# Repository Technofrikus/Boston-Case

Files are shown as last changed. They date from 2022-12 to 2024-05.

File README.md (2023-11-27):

# Boston-Case
Printable Case for the Boston keyboard, based on the metal case design of the original

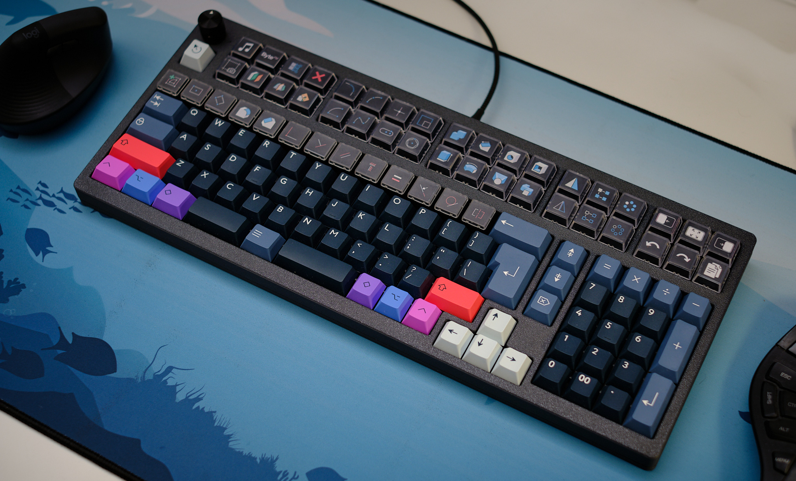
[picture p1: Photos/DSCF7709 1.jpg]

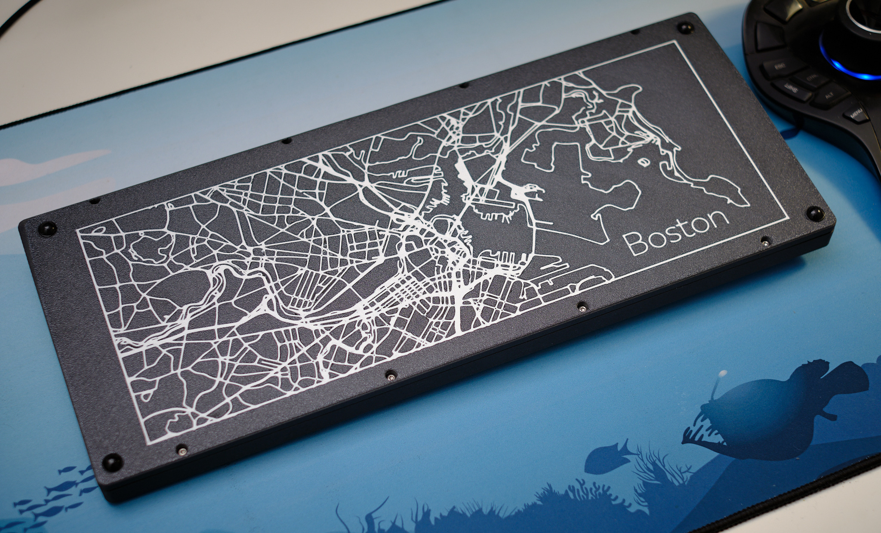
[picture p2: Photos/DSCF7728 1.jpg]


---
### About the Boston

[The Boston](https://github.com/bluepylons/Boston) is a compact 120% keyboard made by Pylon. There was never a real GB of the metal case, so Pylon was so very kind and opensourced the complete Board. There was a GB of a case specifically designed for 3D printing, but I didnt like the design and compromise of a split case.

So I took the metal version and optimized it for printing:
- Removed a lot of material on the inside to save on print time and cost (Alubutyl/Killmat is recommended to put in the inside of the case)
- Added a map of Boston to the underside, inspired by the FR4-version of the Boston. This was a pain to make, because Fusion becomes extremly slow with big SVGs.
- Removed the 3 LEDs for the Locks, because I dont use these functions and wanted a cleaner look (origina verison with LEDs is available)
- Removed the big Lightguide next to the encoder and replaced it with a 1mm hole for plastic lighfiber (not changed in original verison)
- Added a version with **4 degree typing angle**, instead of the 6.5 of the Original (both versions available)

#### Revisions
UPDATE 24.11.2023: Added Version for S1-Daughterboard instead of C3. 

---

## Printing
You need a printer capable of printing a **405mm** object. I had to slighlty increase the printarea of my 400mm Ratrig vCore3 in Software (x-Axis, does not work on y-Axis on the vCore)

---

[STEP files](STEP/)

[STL files](STL/)

[More pictures](Photos/)

[Icons for the Relegendables](https://github.com/Technofrikus/Fusion360-Tool-Icons) 

---
## Hardware needed
- Printed Case (obviously)
- 8x M3x10 cylinder head screws (ISO 4762, button head work too) to connect the two case halfes 
- 10x M3x5 cylinder head screws (ISO 4762, button head work too) to mount the plate on the top case
- 18x M3x3mm threaded insert
- 4x M2x5mm screw for the daughterboard (For the Version with the S1-Daughterboard, use M3x3 Heat inserts and M3x5 screws)
- 4x 10mm feet

### for the original version
For the light pipe etc see the [original documentation](https://github.com/bluepylons/Boston/tree/master/Boston%20-%20Current%20design/Metal%20version).

### for the version without LEDs
- just ~1cm of plastic lightfiber (you have to drill the hole with a 1mm drill, it is printed smaller, for a better fit)

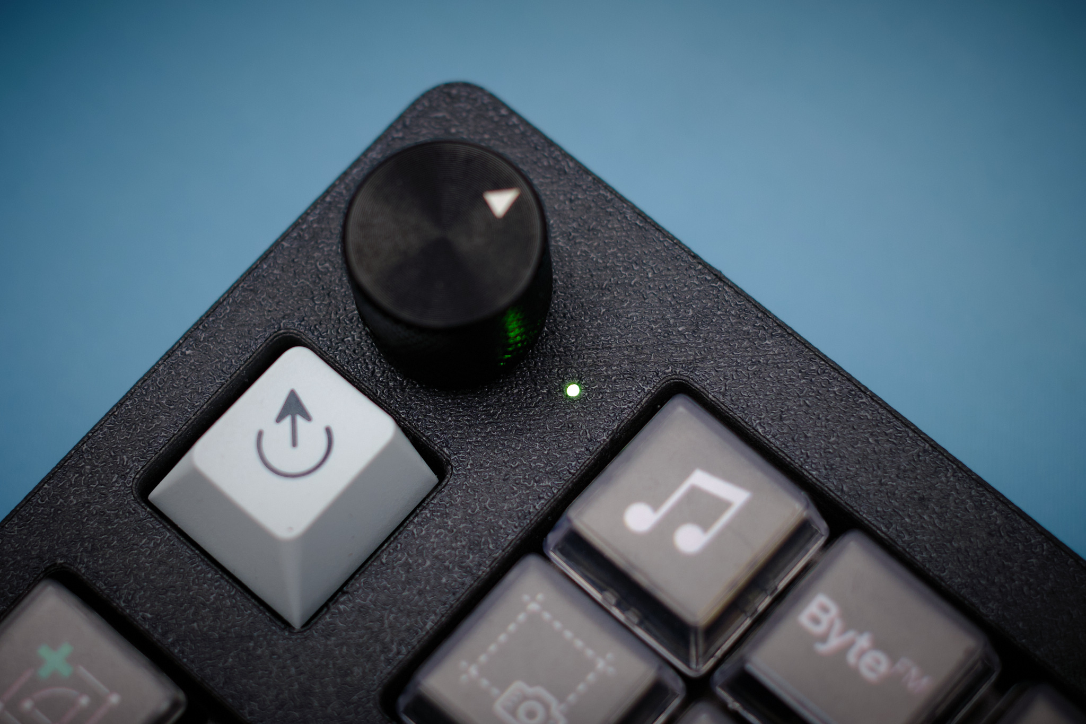
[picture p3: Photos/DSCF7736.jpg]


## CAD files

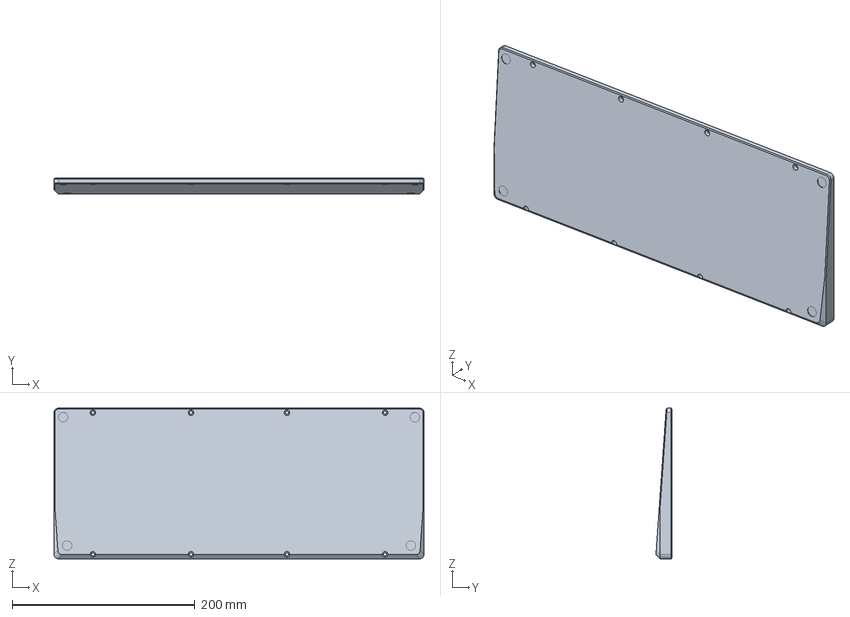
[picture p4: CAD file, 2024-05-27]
STEP/Boston Bottom 4deg no map - for S1 uDB.step
405.0 x 17.7 x 165.0 mm

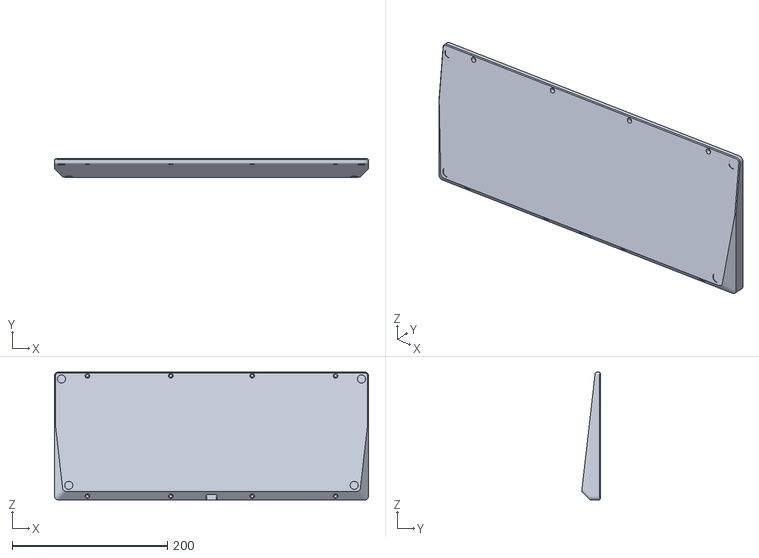
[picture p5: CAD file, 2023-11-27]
STL (more versions in step folder)/Boston Bottom 6.5deg no map - for S1 uDB.stl
405.0 x 24.1 x 165.0

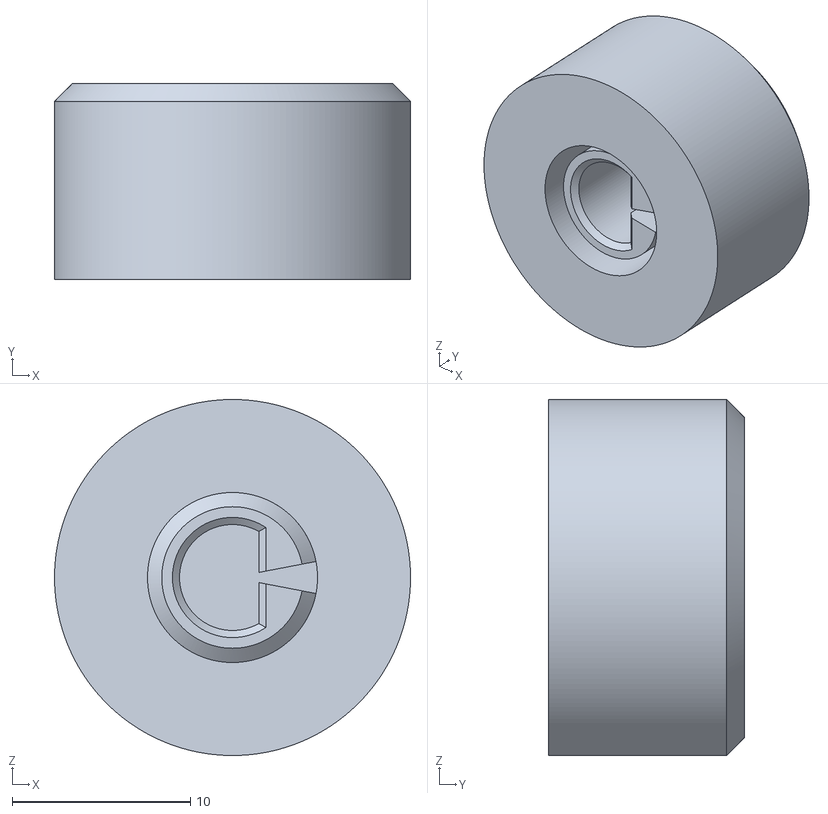
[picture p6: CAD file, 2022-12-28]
STL/Knob.stl
20.0 x 11.0 x 20.0

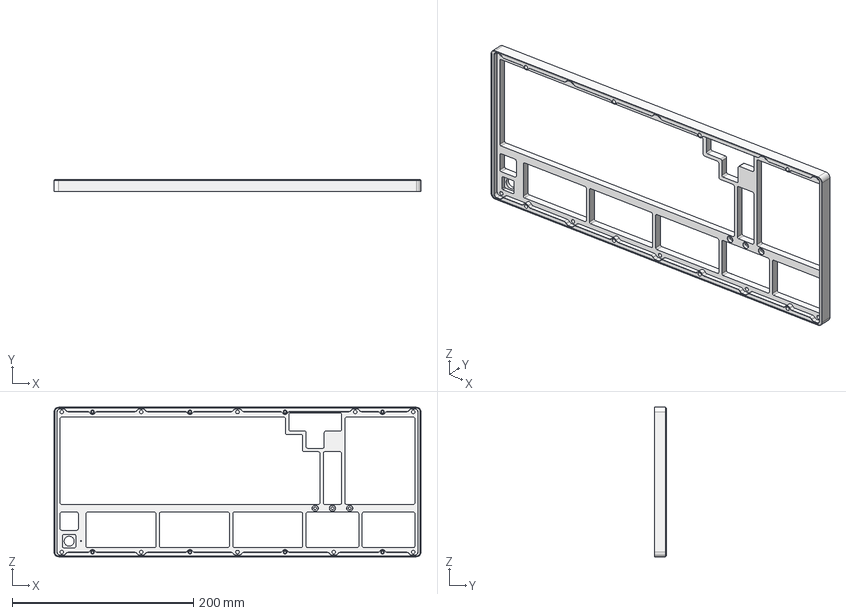
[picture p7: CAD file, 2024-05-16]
STEP/Boston Top - with LEDs but with 1mm lightguide.step
405.0 x 13.5 x 165.0 mm

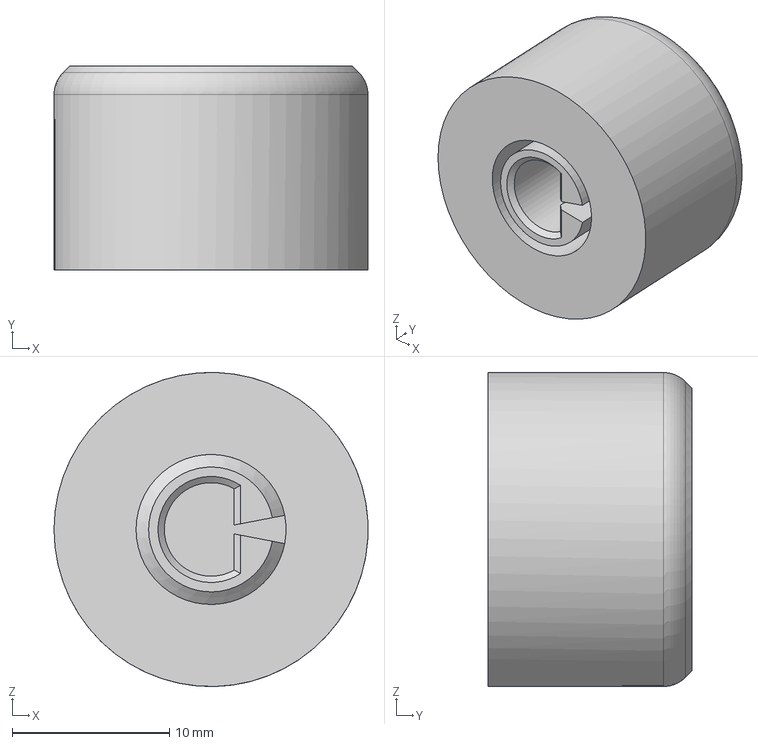
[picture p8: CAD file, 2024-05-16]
STEP/Knob new.step
20.0 x 13.0 x 20.0 mm

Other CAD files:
STL (more versions in step folder)/Boston Bottom 6.5deg no map.stl
STL (more versions in step folder)/Boston Bottom 4deg no map.stl
STEP/Boston Bottom 6.5deg no map - for S1 uDB.step
STL (more versions in step folder)/Boston top without LEDs but for optical fibre.stl
STEP/Boston Top - without LEDs.step
STEP/Boston Top - standard with LEDs.step
STL (more versions in step folder)/Boston top with LEDs.stl
STEP/Boston Bottom 4deg no map.step
STEP/Boston Bottom 6.5deg no map.step
STEP/Boston Metal Case for 3d printing TOP only WITH LEDs (original) for both typing angles.step

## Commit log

2022-12-15 3D added
    [Boston Bottom 4deg no map.step, Boston Bottom 4deg no map.stl, Boston Bottom 6.5deg no map.step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]
2022-12-28 Updated 3D for encoder cutout
    [Boston Metal Case for 3d printing TOP only WITH LEDs (original) for both typing angles.step, Boston Metal Case for 3d printing TOP only with LEDs for both typi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]
2022-12-28 Changed Knobdesign a little
    [Boston top without LEDs but for optical fibre.stl, Knob.stl]
2023-01-02 Updated 3D with correct hole size for daughterboard screws (M2)
    [Boston Bottom 4deg no map.step, Boston Bottom 4deg no map.stl, Boston Bottom 6.5deg no map.step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]
2023-11-24 Added Bottom with mounting for S1 Daughterboard
2023-11-27 Added all file formats for S1-version
    [Boston Bottom 6.5deg no map - for S1 uDB.step, Boston Bottom 6.5deg no map - for S1 uDB.stl, Boston Top - standard with LEDs.step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]
2024-05-16 - Added bottom with 6 degrees and Boston logo - Added Top with LEDs but with 1mm lightguide - Renamed knob and folder to clarify
    [Boston Bottom 4deg no map.stl, Boston Bottom 6.5deg no map - for S1 uDB.stl, Boston Bottom 6.5deg no map.stl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]
2024-05-27 Added 4 degree bottom without map for S1 DB
    [Boston Bottom 4deg no map - for S1 uDB.step]
